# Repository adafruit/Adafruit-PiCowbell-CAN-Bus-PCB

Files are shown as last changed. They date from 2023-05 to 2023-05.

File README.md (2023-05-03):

## Adafruit PiCowbell CAN Bus for Pico - MCP2515 CAN Controller PCB

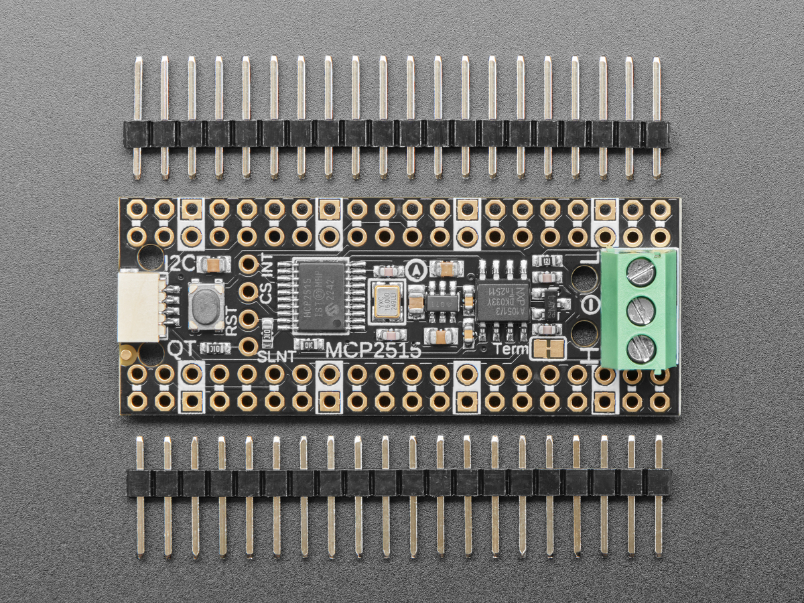
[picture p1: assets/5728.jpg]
<a href="http://www.adafruit.com/products/5728"><br/>
Click here to purchase one from the Adafruit shop</a>

PCB files for the Adafruit PiCowbell CAN Bus for Pico - MCP2515 CAN Controller. 

Format is EagleCAD schematic and board layout
* https://www.adafruit.com/product/5728

### Description

Ding dong! Hear that? It's the PiCowbell ringing, letting you know that the new Adafruit PiCowbell CAN Bus is in stock and ready to assist your Raspberry Pi Pico and Pico W project connect to CAN bus networks for automotive or robotics projects.

CAN Bus is a small-scale networking standard, originally designed for cars and, yes, busses, but is now used for many robotics or sensor networks that need better range and addressing than I2C and don't have the pins or computational ability to talk on Ethernet. CAN is 2 wire differential, which means it's good for long distances and noisy environments.

Messages are sent at about 1Mbps rate - you set the frequency for the bus and then all 'joiners' must match it, and have an address before the packet so that each node can listen in to messages just for it. New nodes can be attached easily because they just need to connect to the two data lines anywhere in the shared net. Each CAN device sends messages whenever it wants, and thanks to some clever data encoding, can detect if there's a message collision and retransmit later. 

If you'd like to connect your Raspberry Pi Pico to a CAN Bus, the Adafruit PiCowbell CAN Bus has a MCP2515 controller and TJA1051/3 transceiver! The controller used is the MCP2515, an extremely popular and well-supported chipset that has drivers in Arduino and CircuitPython and only requires an SPI port and two pins for chip-select and IRQ. Use it to send and receive messages in either standard or extended format at up to 1 Mbps.

We've added a few nice extras to this PiCowBell to make it useful in many common CAN scenarios:

5V charge-pump voltage generator, so even though you are running 3.3V on a Pico board, it will generate a nice clean 5V as required by the transceiver.
3.5mm terminal block pre-soldered in to get quick access to the High and Low data lines as well as a ground pin.
120-ohm termination resistor on board, you can remove the termination easily by cutting the jumper marked Term on the top of the board.
Pre-connected CS and INT pins on Pico GPIO #20 and #21. You can cut the bottom solder jumpers and use the breakout pads to connect to any two IO pins you like
Each order comes with an assembled PCB and header. You will need to solder in the header yourself, but it's a quick task.

Please Note! There are a lot of possible configurations, and we stock various headers depending on how you want to solder and attach. Especially if you want the Pico on top so that the BOOTSEL button and LED are accessible.

1. Use the Pico Stacking Headers if you want to be able to plug into a breadboard or other accessory with sockets.
2. Use the Pico Socket Headers if you want to plug directly in and have a nice solid connection that doesn't have any poking-out-bits.
3. Use the Short Socket Headers for a very slim but pluggable design; note that you'll want to trim down the Pico's headers or use the short plug headers on the Pico to have a skinny sandwich.
4. Solder the PCB directly to the Pico headers - of course, this is very compact and inexpensive, but you won't be able to remove the PiCowbell.

The PiCowbell CAN Bus provides you with:

* Right angle JST SH connector for I2C / Stemma QT / Qwiic connection. Provides 3V, GND, IO4 (SDA), and IO5 (SCL)
* Reset button - Press to restart your program
* Every pad on the 'bell has a duplicate hole pad next to them for solder-jumpering
* The ground pads have white silkscreen rectangles to easily identify, plus one long ground strip near the reset button
* Gold-plated pads for easy soldering

If using the Philhower Arduino core, the Wire peripheral is already set up to use IO4 and IO5, and SPI is default on IO16, IO18 and IO19. If using CircuitPython or MicroPython, you'll need to let the code know to look at 4+5 for SDA+SCL pins, and configure the SPI port for SCK=18, MOSI=19 and MISO=16.

### License

Adafruit invests time and resources providing this open source design, please support Adafruit and open-source hardware by purchasing products from [Adafruit](https://www.adafruit.com)!

Designed by Limor Fried/Ladyada for Adafruit Industries.

Creative Commons Attribution/Share-Alike, all text above must be included in any redistribution. 
See license.txt for additional details.

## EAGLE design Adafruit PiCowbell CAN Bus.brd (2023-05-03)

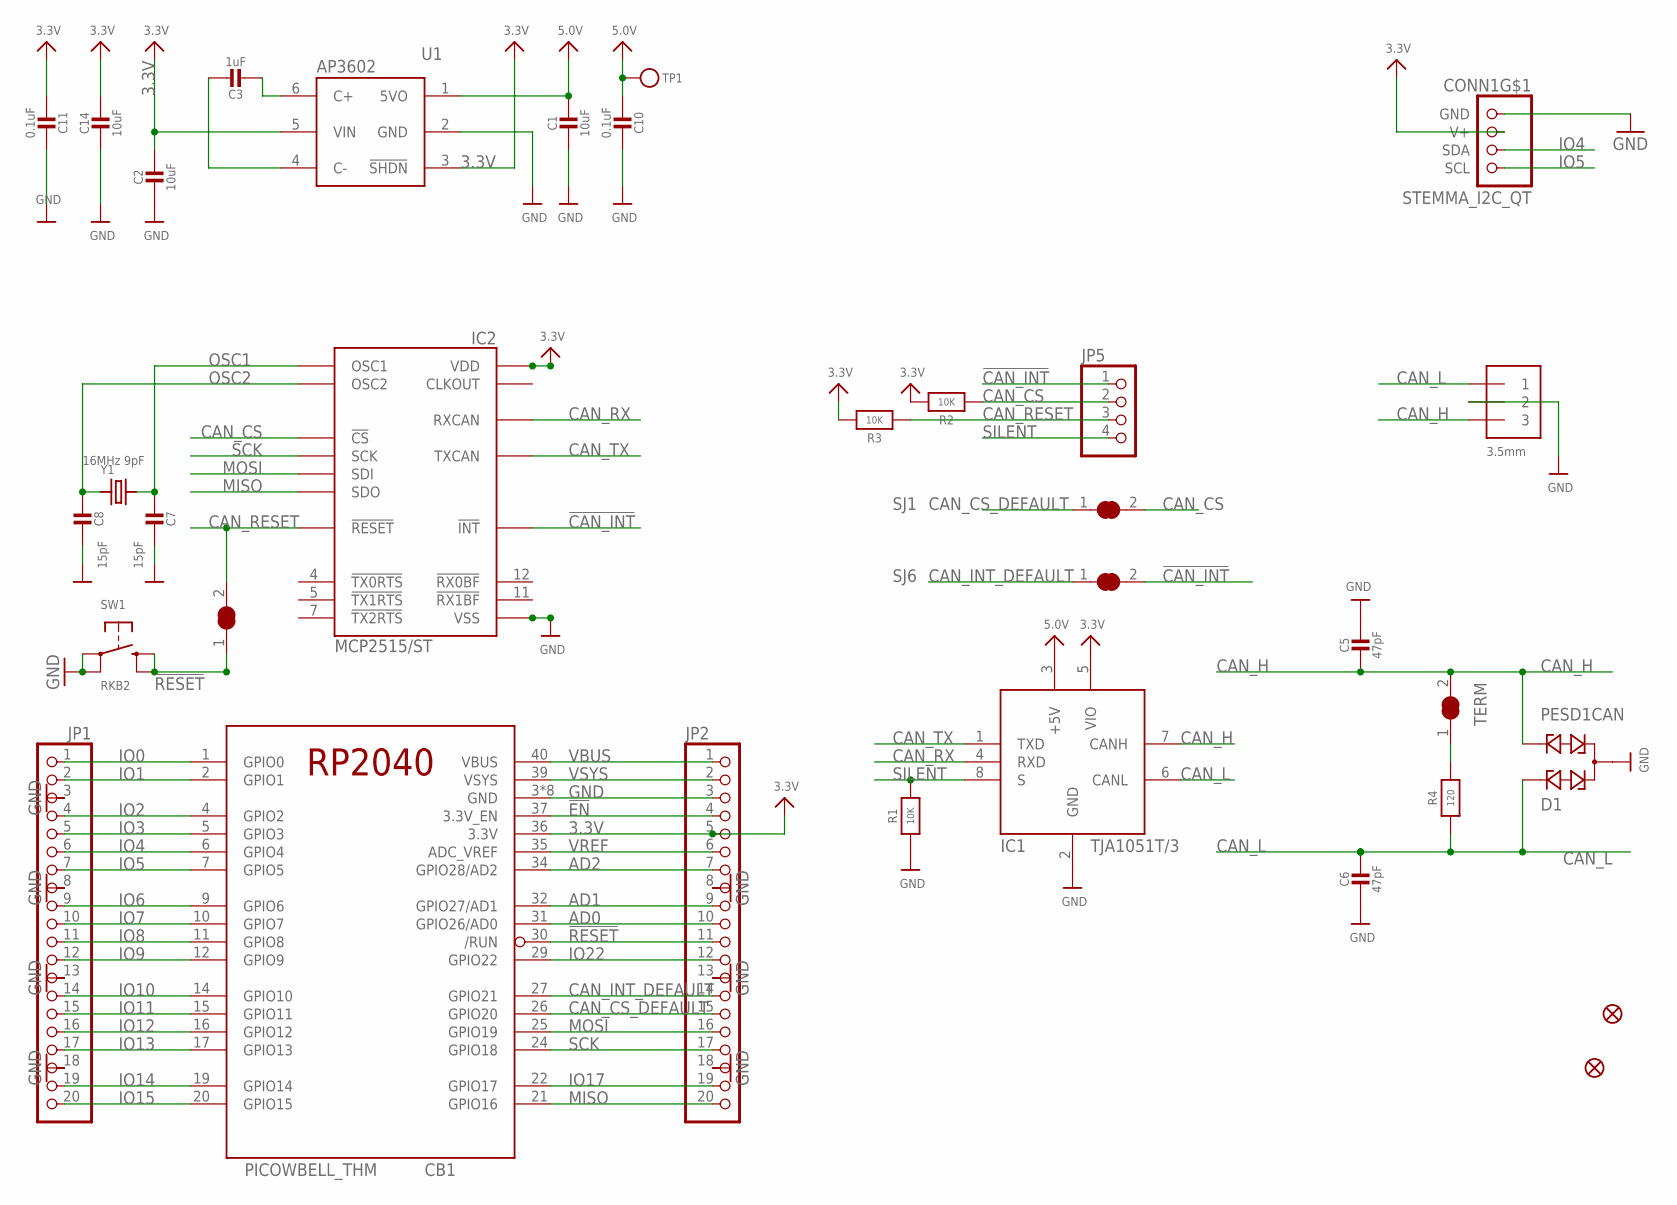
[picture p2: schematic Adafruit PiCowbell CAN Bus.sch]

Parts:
C1, C2, C14: 10uF; 0805-NO
C3: 1uF; 0805-NO
C5, C6: 47pF; 0603-NO
C7, C8: 15pF; 0603-NO
C10, C11: 0.1uF; 0603-NO
CAN: 3.5mm; TERMBLOCK_1X3-3.5MM
CB1: PICOWBELL_THM
CONN1: STEMMA_I2C_QT; JST_SH4
D1: PESD1CAN; SOT23
FID1, FID2: FIDUCIAL_1MM
IC1: TJA1051T/3; SOIC8_150MIL
IC2: MCP2515/ST; SSOP20
JP1, JP2: HEADER-1X20_70MIL; 1X20_ROUND_70MIL
JP5: HEADER-1X4ROUND; 1X04_ROUND
R1, R2, R3: 10K; 0603-NO
R4: 120; 0603-NO
SJ1, SJ5, SJ6: SOLDERJUMPER_CLOSED; SOLDERJUMPER_CLOSEDWIRE
SW1: RKB2; BTN_RKB2_4.6X2.8
TERM: SOLDERJUMPER_CLOSED; SOLDERJUMPER_CLOSEDWIRE
TP1: TESTPOINTROUND1.5MM; TESTPOINT_ROUND_1.5MM
U1: AP3602; SOT23-6
Y1: 16MHz 9pF; CRYSTAL_3.2X2.5

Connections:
3.3V: C2.1, C11.2, C14.1, CB1.36 (3.3V), CONN1.2 (V+), IC1.5 (VIO), IC2.20 (VDD), JP2.5, R2.2, R3.2, U1.3 (!SHDN), U1.5 (VIN)
5.0V: C1.1, C10.2, IC1.3 (+5V), TP1.P$1, U1.1 (5VO)
!CAN_INT: IC2.13 (!INT), JP5.1, SJ6.2
!EN: CB1.37 (3.3V_EN), JP2.4
!RESET: CB1.30 (/RUN), JP2.11, SJ5.1, SW1.B (S), SW1.B' (S1)
AD0: CB1.31 (GPIO26/AD0), JP2.10
AD1: CB1.32 (GPIO27/AD1), JP2.9
AD2: CB1.34 (GPIO28/AD2), JP2.7
CAN_CS: IC2.18 (!CS), JP5.2, R2.1, SJ1.2
CAN_CS_DEFAULT: CB1.26 (GPIO20), JP2.15, SJ1.1
CAN_H: C5.2, CAN.3, D1.2, IC1.7 (CANH), TERM.2
CAN_INT_DEFAULT: CB1.27 (GPIO21), JP2.14, SJ6.1
CAN_L: C6.1, CAN.1, D1.1, IC1.6 (CANL), R4.1
CAN_RESET: IC2.19 (!RESET), JP5.3, R3.1, SJ5.2
CAN_RX: IC1.4 (RXD), IC2.2 (RXCAN)
CAN_TX: IC1.1 (TXD), IC2.1 (TXCAN)
GND: C1.2, C2.2, C5.1, C6.2, C7.1, C8.1, C10.1, C11.1, C14.2, CAN.2, CB1.3 (GND), CB1.8 (GND), CB1.13 (GND), CB1.18 (GND), CB1.23 (GND), CB1.28 (GND), CB1.33 (GND), CB1.38 (GND), CONN1.1 (GND), D1.3, IC1.2 (GND), IC2.10 (VSS), JP1.3, JP1.8, JP1.13, JP1.18, JP2.3, JP2.8, JP2.13, JP2.18, R1.1, SW1.A, SW1.A' (P1), U1.2 (GND)
IO0: CB1.1 (GPIO0), JP1.1
IO1: CB1.2 (GPIO1), JP1.2
IO2: CB1.4 (GPIO2), JP1.4
IO3: CB1.5 (GPIO3), JP1.5
IO4: CB1.6 (GPIO4), CONN1.3 (SDA), JP1.6
IO5: CB1.7 (GPIO5), CONN1.4 (SCL), JP1.7
IO6: CB1.9 (GPIO6), JP1.9
IO7: CB1.10 (GPIO7), JP1.10
IO8: CB1.11 (GPIO8), JP1.11
IO9: CB1.12 (GPIO9), JP1.12
IO10: CB1.14 (GPIO10), JP1.14
IO11: CB1.15 (GPIO11), JP1.15
IO12: CB1.16 (GPIO12), JP1.16
IO13: CB1.17 (GPIO13), JP1.17
IO14: CB1.19 (GPIO14), JP1.19
IO15: CB1.20 (GPIO15), JP1.20
IO17: CB1.22 (GPIO17), JP2.19
IO22: CB1.29 (GPIO22), JP2.12
MISO: CB1.21 (GPIO16), IC2.17 (SDO), JP2.20
MOSI: CB1.25 (GPIO19), IC2.16 (SDI), JP2.16
unnamed: C3.2, U1.6 (C+)
unnamed: C3.1, U1.4 (C-)
unnamed: R4.2, TERM.1
OSC1: C7.2, IC2.9 (OSC1), Y1.2
OSC2: C8.2, IC2.8 (OSC2), Y1.1
SCK: CB1.24 (GPIO18), IC2.14 (SCK), JP2.17
SILENT: IC1.8 (S), JP5.4, R1.2
VBUS: CB1.40 (VBUS), JP2.1
VREF: CB1.35 (ADC_VREF), JP2.6
VSYS: CB1.39 (VSYS), JP2.2

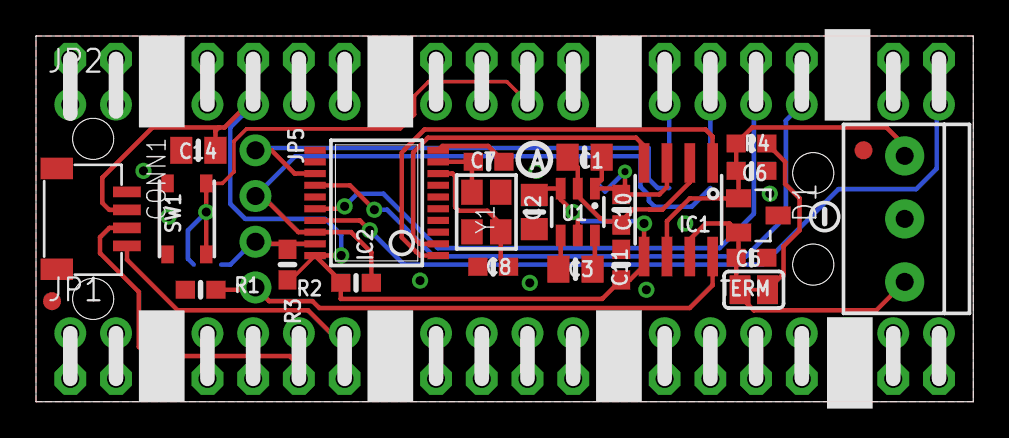
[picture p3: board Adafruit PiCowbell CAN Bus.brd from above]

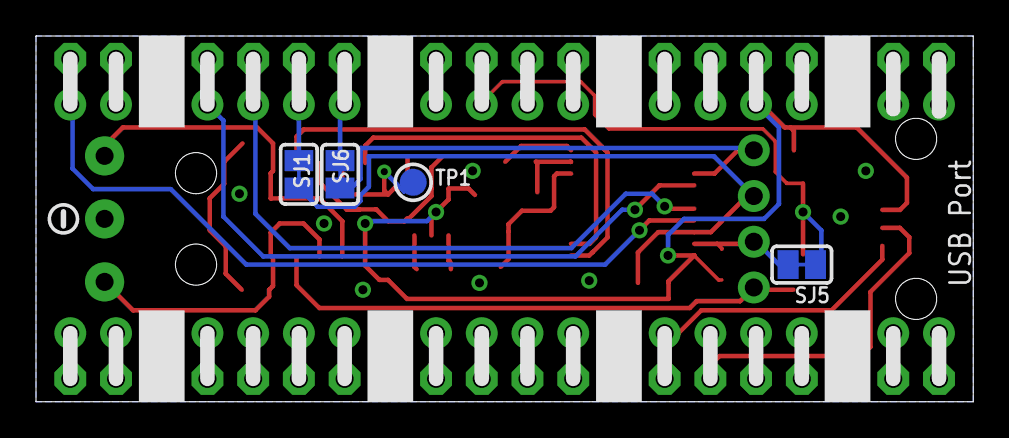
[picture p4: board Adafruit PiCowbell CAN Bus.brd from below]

Board: 2 copper layers, 52.1 x 20.3 mm, 84 parts (43 on the bottom side), 47 nets.

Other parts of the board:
PLABEL36: PLABEL36
PLABEL37: PLABEL37
PLABEL38: PLABEL38
PLABEL40: PLABEL40
PLABEL41: PLABEL41
PLABEL42: PLABEL42
PLABEL43: PLABEL43
PLABEL44: PLABEL44
PLABEL45: PLABEL45
PLABEL46: PLABEL46
PLABEL47: PLABEL47
PLABEL49: PLABEL49
PLABEL50: PLABEL50
PLABEL51: PLABEL51
PLABEL52: PLABEL52
PLABEL53: PLABEL53
PLABEL54: PLABEL54
PLABEL55: PLABEL55
PLABEL56: PLABEL56
PLABEL57: PLABEL57
PLABEL58: PLABEL58
PLABEL59: PLABEL59
PLABEL60: PLABEL60
PLABEL61: PLABEL61
PLABEL62: PLABEL62
PLABEL63: PLABEL63
PLABEL64: PLABEL64
PLABEL65: PLABEL65
PLABEL66: PLABEL66
PLABEL67: PLABEL67
PLABEL68: PLABEL68
PLABEL69: PLABEL69
PLABEL70: PLABEL70
PLABEL71: PLABEL71
PLABEL72: PLABEL72
PLABEL73: PLABEL73
PLABEL74: PLABEL74
PLABEL75: PLABEL75
PLABEL76: PLABEL76
PLABEL77: PLABEL77
PLABEL78: PLABEL78
PLABEL79: PLABEL79
PLABEL80: PLABEL80
PLABEL81: PLABEL81
PLABEL82: PLABEL82
PLABEL83: PLABEL83
PLABEL84: PLABEL84
PLABEL85: PLABEL85
U$2, U$34: SYMBOL_MINUS
U$11: PCBFEAT-REV-040

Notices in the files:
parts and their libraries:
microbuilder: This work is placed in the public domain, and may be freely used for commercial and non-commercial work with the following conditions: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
